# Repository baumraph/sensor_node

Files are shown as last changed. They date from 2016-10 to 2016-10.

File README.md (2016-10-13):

# sensor_node
## Warning: This board has not been tested yet.

The sensor node is a board for low power wireless sensor networks.
It contains three circuits:

  1. ATMEGA328P-AU (similar circuit to an Arduino Pro Mini)
  2. NCP1402 for stepping up the voltage, which makes it possible to use only one battery.
  3. NRF24L01+ 2.4 GHz RF with external antenna
  
It is also possible to measure the voltage of the battery using pin A0.

Since the board has a similar layout as an Arduino Pro Mini, the Arduino IDE can be used to program the board.
A common library (e.g. RF24NETWORK) can be used for the software side.

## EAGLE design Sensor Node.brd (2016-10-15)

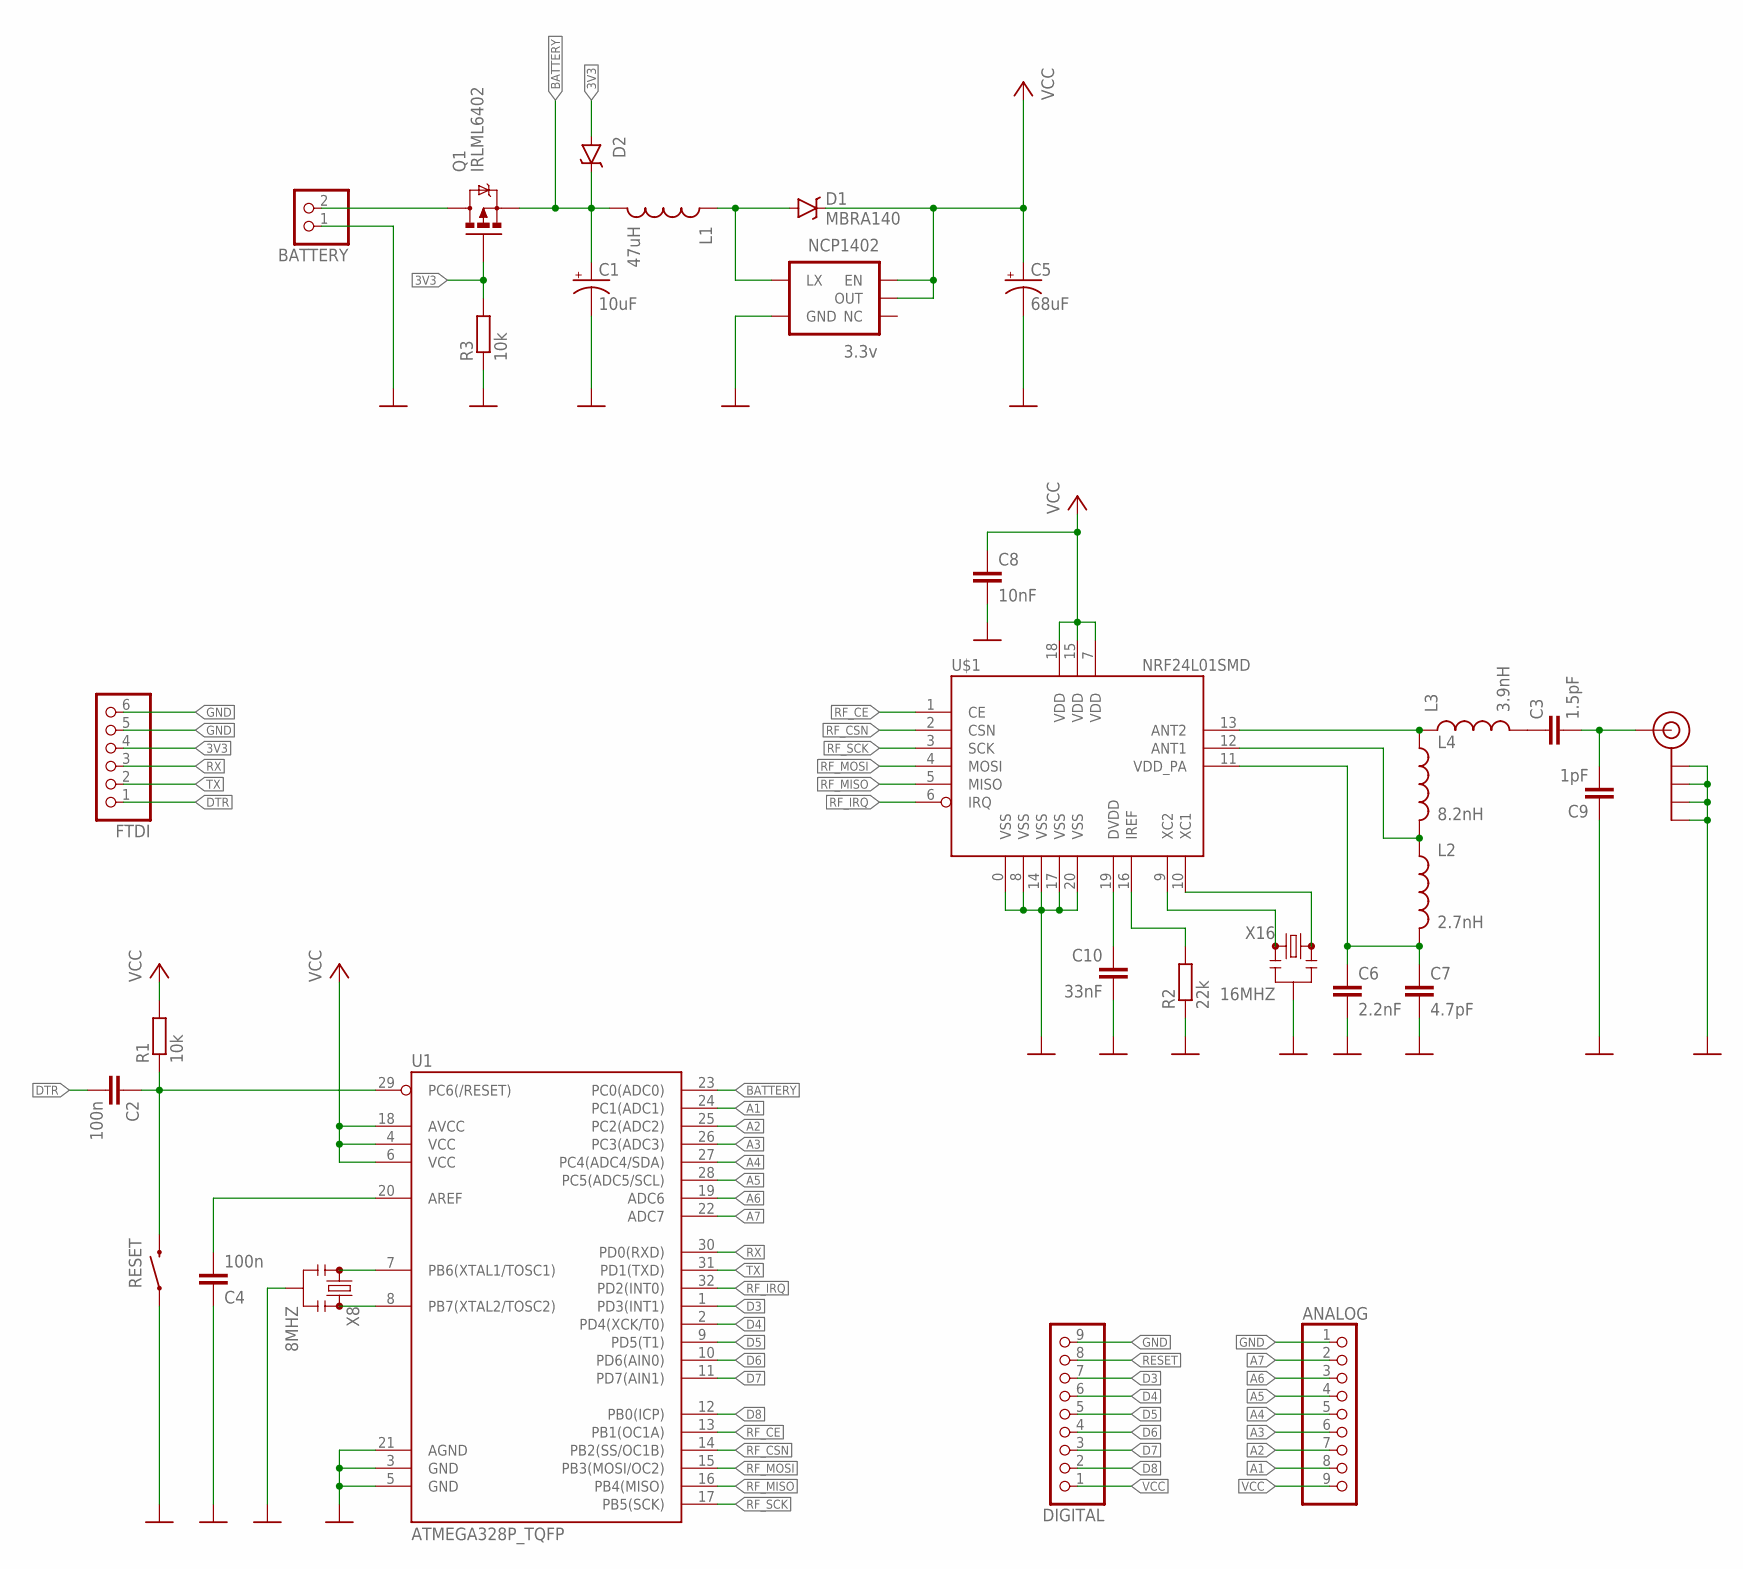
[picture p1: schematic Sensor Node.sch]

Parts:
ANALOG: PINHD-1X9; 1X09
BATTERY: PINHD-1X2; 1X02
C1: 10uF; EIA3216-KIT
C2, C4: 100n; C0402
C3: 1.5pF; C0402
C5: 68uF; EIA3528-KIT
C6: 2.2nF; C0402
C7: 4.7pF; C0402
C8: 10nF; C0402
C9: 1pF; C0402
C10: 33nF; C0402
D1, D2: MBRA140; SMA-DIODE
DIGITAL: PINHD-1X9; 1X09
FTDI: PINHD-1X6; 1X06
J$1: SMA_EDGE; SMA-EDGE
L1: 47uH; CR54
L2: 2.7nH; C0402
L3: 3.9nH; C0402
L4: 8.2nH; C0402
NCP1402: 3.3v; SOT23-5
Q1: IRLML6402; SOT23-3
R1, R3: 10k; R0402
R2: 22k; R0402
RESET: SWITCH-MOMENTARY-2SMD-1101NE; TACTILE-SWITCH-1101NE
U1: ATMEGA328P_TQFP; TQFP32-08
U$1: NRF24L01SMD; QFN20
X8: 8MHZ; RESONATOR-SMD
X16: 16MHZ; RESONATOR-SMD

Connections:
3V3: D2.A, FTDI.4, Q1.1 (G), R3.2
A1: ANALOG.8, U1.24 (PC1(ADC1))
A2: ANALOG.7, U1.25 (PC2(ADC2))
A3: ANALOG.6, U1.26 (PC3(ADC3))
A4: ANALOG.5, U1.27 (PC4(ADC4/SDA))
A5: ANALOG.4, U1.28 (PC5(ADC5/SCL))
A6: ANALOG.3, U1.19 (ADC6)
A7: ANALOG.2, U1.22 (ADC7)
BAT+: BATTERY.2, Q1.3 (D)
BATTERY: C1.A (+), D2.C, L1.P$2 (2), Q1.2 (S), U1.23 (PC0(ADC0))
D3: DIGITAL.7, U1.1 (PD3(INT1))
D4: DIGITAL.6, U1.2 (PD4(XCK/T0))
D5: DIGITAL.5, U1.9 (PD5(T1))
D6: DIGITAL.4, U1.10 (PD6(AIN0))
D7: DIGITAL.3, U1.11 (PD7(AIN1))
D8: DIGITAL.2, U1.12 (PB0(ICP))
DTR: C2.2, FTDI.1
GND: ANALOG.1, BATTERY.1, C1.C (-), C4.1, C5.C (-), C6.2, C7.2, C8.2, C9.1, C10.2, DIGITAL.9, FTDI.5, FTDI.6, J$1.GND@0 (GND), J$1.GND@1 (GND), J$1.GND@2 (GND), J$1.GND@3 (GND), NCP1402.4 (GND), R2.1, R3.1, RESET.1, U1.3 (GND), U1.5 (GND), U1.21 (AGND), U$1.0 (VSS), U$1.8 (VSS), U$1.14 (VSS), U$1.17 (VSS), U$1.20 (VSS), X8.2, X16.2
unnamed: D1.A, L1.P$1 (1), NCP1402.5 (LX)
unnamed: C3.1, L3.2
unnamed: C4.2, U1.20 (AREF)
unnamed: L3.1, L4.1, U$1.13 (ANT2)
unnamed: U1.7 (PB6(XTAL1/TOSC1)), X8.1
unnamed: U1.8 (PB7(XTAL2/TOSC2)), X8.3
unnamed: L2.1, L4.2, U$1.12 (ANT1)
unnamed: R2.2, U$1.16 (IREF)
unnamed: C3.2, C9.2, J$1.SIG (SIGNAL)
unnamed: C10.1, U$1.19 (DVDD)
unnamed: C6.1, C7.1, L2.2, U$1.11 (VDD_PA)
unnamed: U$1.9 (XC2), X16.3
unnamed: U$1.10 (XC1), X16.1
RESET: C2.1, DIGITAL.8, R1.1, RESET.2, U1.29 (PC6(/RESET))
RF_CE: U1.13 (PB1(OC1A)), U$1.1 (CE)
RF_CSN: U1.14 (PB2(SS/OC1B)), U$1.2 (CSN)
RF_IRQ: U1.32 (PD2(INT0)), U$1.6 (IRQ)
RF_MISO: U1.16 (PB4(MISO)), U$1.5 (MISO)
RF_MOSI: U1.15 (PB3(MOSI/OC2)), U$1.4 (MOSI)
RF_SCK: U1.17 (PB5(SCK)), U$1.3 (SCK)
RX: FTDI.3, U1.30 (PD0(RXD))
TX: FTDI.2, U1.31 (PD1(TXD))
VCC: ANALOG.9, C5.A (+), C8.1, D1.C, DIGITAL.1, NCP1402.1 (EN), NCP1402.2 (OUT), R1.2, U1.4 (VCC), U1.6 (VCC), U1.18 (AVCC), U$1.7 (VDD), U$1.15 (VDD), U$1.18 (VDD)

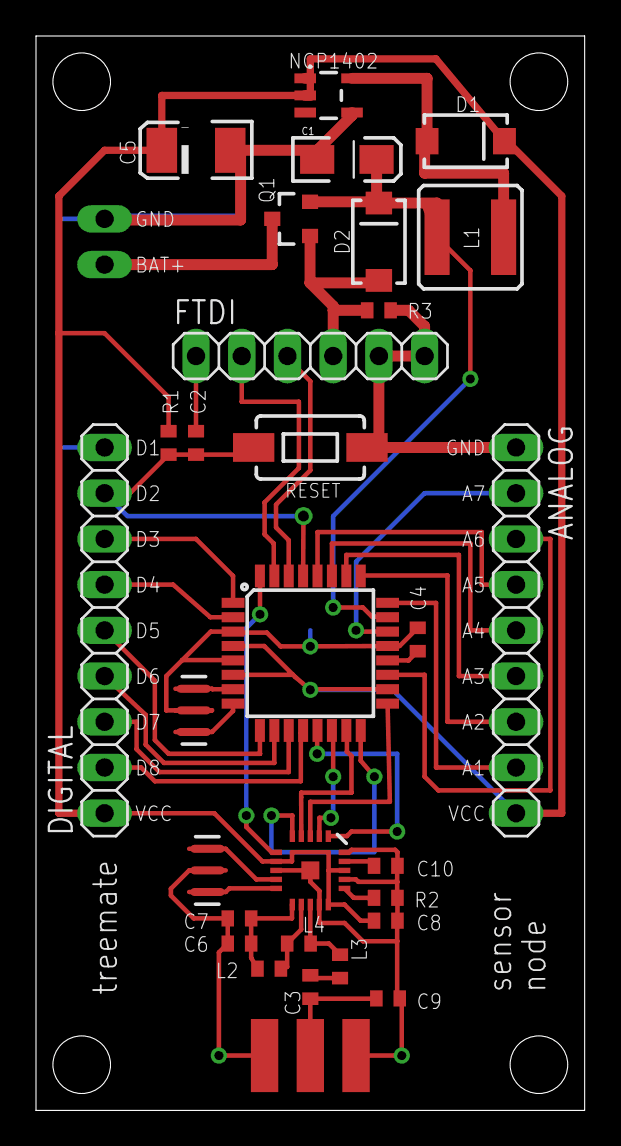
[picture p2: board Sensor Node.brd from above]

Board: 2 copper layers, 30.5 x 59.7 mm, 31 parts (1 on the bottom side), 41 nets.

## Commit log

2016-10-13 Initial commit
    Add schematic and board
    [Sensor Node.brd, Sensor Node.sch]
2016-10-14 Distance optimization
    Reduce the distance between the RF components
    Make vias round
    [Sensor Node.brd]
2016-10-15 Refactoring
    Replace the FTDI pinheader
    Remove unwanted text
    Move and resize text
    [Sensor Node.brd, Sensor Node.sch]

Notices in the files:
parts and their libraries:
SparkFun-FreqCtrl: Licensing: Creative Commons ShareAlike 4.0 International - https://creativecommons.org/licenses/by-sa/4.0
